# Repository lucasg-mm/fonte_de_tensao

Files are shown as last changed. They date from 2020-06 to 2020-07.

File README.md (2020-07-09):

# Projeto 1 da Disciplina SCC0180: Fonte de Tensão

## Autor
Lucas Gabriel Mendes Miranda, 10265892

## Objetivo
Projetar uma fonte de tensão que forneça, na saída, uma tensão entre 3V e 12V com capacidade de 100mA.

## Diagrama da Fonte

Imagem do Circuito

## Lista de Componentes Utilizados

| Nome do Componente | Valor | Preço |
| --- | --- | --- |
| [Transformador](https://www.soldafria.com.br/componentes-eletronicos/transformador/2a/transformador-15v-2a-entrada-110-220vac) | 15V 2A | R$39,82 |
| [Diodo Zener BZX55C](https://www.baudaeletronica.com.br/diodo-zener-bzx55c-13v-0-5w.html) | 13V 0,5W | R$ 0,09 |
| [Resistor](https://www.baudaeletronica.com.br/resistor-1k8-5-1-4w.html) | 1,8k 5% (1/4W) | R$ 0,08 |
| [Resistor](https://www.baudaeletronica.com.br/resistor-1k8-1-2w.html) | 1k 5% (1/2W) | R$ 0,14 |
| [Resistor](https://www.baudaeletronica.com.br/resistor-2k2-5-1-4w.html) | 2,2k 5% (1/4W) | R$ 0,08 |
| [Potenciômetro Linear](https://www.baudaeletronica.com.br/potenciometro-linear-de-5k-5000.html) | 5k (0,2W) | R$ 1,09 |
| [Capacitor Eletrolítico](https://www.baudaeletronica.com.br/capacitor-eletrolitico-470uf-25v.html) | 470 uF / 25V | R$ 0,33 |
| 4 [Diodos 1N5404](https://www.baudaeletronica.com.br/diodo-1n5404.html) (para a ponte) | 3A | R$ 0,36 (cada)|
| [LED difuso 5mm vermelho](https://www.baudaeletronica.com.br/led-difuso-5mm-vermelho.html) | 2V 20mA | R$ 0,24 |
| [Transistor NPN BC337](https://www.baudaeletronica.com.br/transistor-npn-bc337.html) | VCEO = 45V, IC = 500mA | R$ 0,17 |

## Partes do Circuito e Justificativa dos Componentes

### Fonte de Tensão AC de 127V
A fonte foi projetada para funcionar com o fornecimento de uma tensão de 127V (RMS) em corrente alternada (AC). O simulador usado (Falstad) permite apenas definir a tensão máxima (peak) de uma fonte AC. Mas, sabemos que:



Então a tensão máxima dessa fonte foi ajustada para 179.6V no simulador. 

### Transformador
O transformador tem como objetivo diminuir o valor da tensão de 127V. Para determinar o valor do transformador necessário, foi preciso realizar alguns cálculos:

* Sabemos que a nossa fonte precisa fornecer no máximo **12V**

* Cada diodo tem uma queda de **0.7V**

* O circuito regulador precisa de aproximadamente **8.46V** para funcionar (quando a fonte fornece *12V*)

Somando os valores em negrito, temos uma tensão de pico de aproximadamente 21.16V, por isso, precisamos de um transformador de, no mínimo, 15V RMS, capaz de fornecer 500 mA.

### Ponte de Diodos (Rectifier)
A ponte de diodos converte a tensão AC do transformador numa tensão DC pulsante. 

### Capacitor (Filtro)
O capacitor diminui os pulsos da tensão fornecida pela ponte de diodos. O capacitor está submetido a uma tensão de aproximadamente 20V, porém, foi listado na lista de materiais com 25V para evitar queimar o dispositivo (temos uma margem de segurança de 5V).

### LED
Apenas para indicar qua a fonte está ligada. Possui um resistor de 1k conectado em série para não queimar o diodo.

### Circuito Regulador
Esse circuito elimina o ripple da tensão fornecida pelo filtro, resultando na tensão DC entre 3V e 12V desejada (ela é definida manipulando o potenciômetro).

### Saída
Representamos o dispositivo a ser alimentado por um resistor de 120 ohms.

## Link para o Circuito no Falstad
http://tinyurl.com/ycgv9rr6

## Esquemático Feito no EAGLE
Corresponde ao arquivo `fonte.sch`

Imagem do Esquemático

## PCB Feito no EAGLE
Corresponde ao arquivo `fonte.brd`

Imagem do PCB

## Vídeo

https://www.youtube.com/watch?v=4Xhk5OuTBfk

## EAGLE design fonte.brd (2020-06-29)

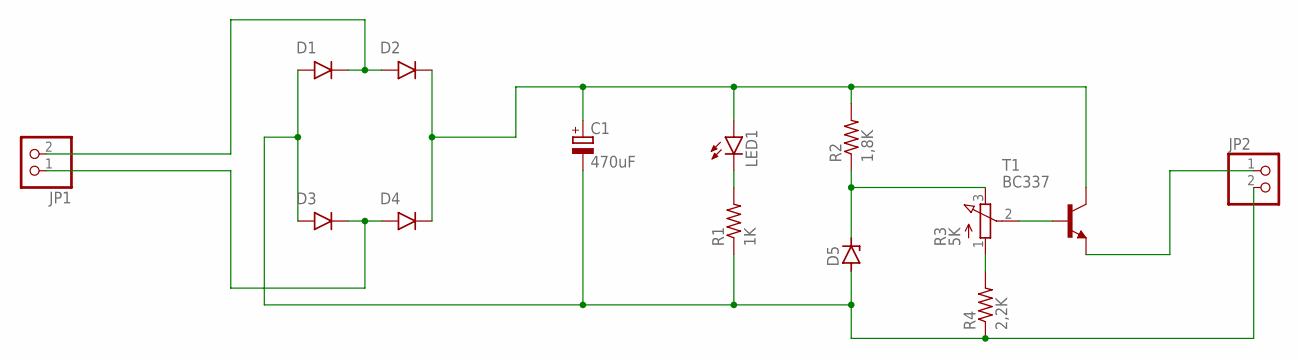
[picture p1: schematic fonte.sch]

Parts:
C1: 470uF; E3,5-10
D1, D2, D3, D4: 1N4001; DO41-10
D5: ZENER-DIODEDO34-7; DO34Z7
JP1, JP2: PINHD-1X2; 1X02
LED1: LED5MM
R1: 1K; 0309/12
R2: 1,8K; 0309/12
R3: 5K; 3RP/1610N
R4: 2,2K; 0309/12
T1: BC337; TO92

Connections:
unnamed: D1.C (CATHODE), D2.A (ANODE), JP1.2
unnamed: D3.C (CATHODE), D4.A (ANODE), JP1.1
unnamed: C1.-, D1.A (ANODE), D3.A (ANODE), D5.A, JP2.2, R1.1, R4.1
unnamed: C1.+, D2.C (CATHODE), D4.C (CATHODE), LED1.A, R2.2, T1.3 (C)
unnamed: D5.C, R2.1, R3.3 (E)
unnamed: R3.1 (A), R4.2
unnamed: LED1.K (C), R1.2
unnamed: R3.2 (S), T1.2 (B)
unnamed: JP2.1, T1.1 (E)

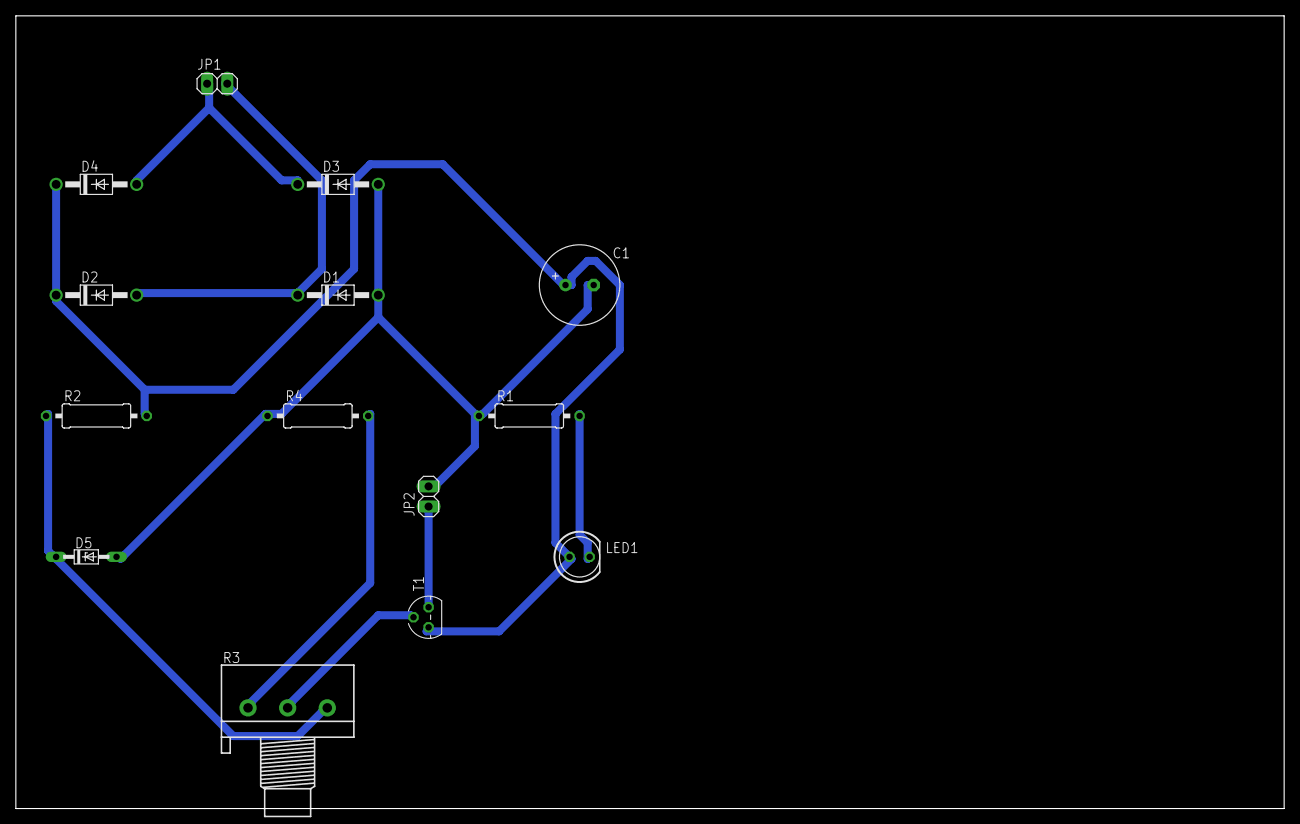
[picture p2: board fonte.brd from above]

Board: 2 copper layers, 160.0 x 100.0 mm, 14 parts (0 on the bottom side), 9 nets.

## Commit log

2020-06-28 Adiciona foto do circuito, lista de componentes e link para a simulação no Falstad
2020-06-29 Adiciona arquivos do projeto no EAGLE
    [fonte.brd, fonte.sch]
